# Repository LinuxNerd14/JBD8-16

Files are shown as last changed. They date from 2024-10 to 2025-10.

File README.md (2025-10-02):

# The JBD8-16
Current Deign
A computer with the skeleton of the BE6502 by the revered [Ben Eater](https://eater.net/) with the ultimate goal of running DOOM and making a decent platform for programing in asembly or C at a very fundemental level.

    This computer is currently still deep in hardware development but has a diverse set of planned features like hardware based random numbers and way more RAM than what is reasonable along with an implimentation of the VERA by the [8BitGuy](https://www.the8bitguy.com/).

This is by far not a finished project as these features awaiting implimentation:

1. Memory bank
2. Proper random number generator
3. Micro SD card
4. Better display or VGA output
5. Easily reproducable PCB's

List of contributers:

1. [Brian Dean Ullery](https://github.com/NonzeroCornet)

2. [Joshua Lin Yuan]([LinuxNerd14 (Joshua Yuan) · GitHub](https://github.com/LinuxNerd14))

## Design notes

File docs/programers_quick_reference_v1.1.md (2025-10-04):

Quick Refrence guide for addresses:
See docs for details
VIA:
	$4460 = In/Oout Register B
	$4461 = In/Out Register A 
	$4462 = Data Direction for register B
	$463 = Data Direction for register A
	$4464 = Timer 1 Low-Order Latches and Low-Order Counter 
	$4465 = T1 High-Order Counter
	$4466 = T1 Low-Order Latches
	$4467 = T1 High-Order Latches
	$4468 = T2 Low-Order Latches and Low-Order Counter
	$4469 = T2 High-Order Counter
	$446a = Shift Register
	$446b = Auxiliary Control Register
	$446c = Peripheral Control Register
	$446d = Interrupt Flag Register
	$446e = Interrupt Enable Register
	$446f = Same as 4461 except for no handshake

SERIAL PORT:
	$4470 = UART Data
	$4471 = UART Status
	$4472 = UART Command
	$4473 = UART control

TO FIX THE HARDWARE BUG. Wait a certain time based on cpu clock speed.
This equation sets the value needed for the below code to set the perfect delay. If in doubt, just max it out.
~~~
X = ((1/[BAUD RATE]) * ([CPU clock in Hz]) * 10)/5.208
~~~
This is just a sample piece of code. You can try to implient it if you want but I would recommend making your own for your situation.
~~~
tx_delay:
 ldx #$ff   ; deleay determined by baud rate and cpu clok equation is below to set proper number
tx_delay_1:; ((1/[BAUD RATE]) * ([CPU clok in Hz]) * 10)/5.208 = value to load into X; be sure to round up to the nearest whole number
 dex
 bne tx_delay_1
~~~

Fixed table in hex, inclusive   sector size decimal		sector size hex
ROM     C180 > FFFF             16000				3E80 
SCM     4480 > C17F             32000				7D00
MISC    4474 > 447F             12				C
UART    4470 > 4473             4				4
VIA     4460 > 446F             16				10
VERA    4440 > 445F             32				20
RAND    443F                    1				1
CS      443E                    1(ACTIVE HIGH in hardware)	1
OS      0000 > 443D             17470				443E

In Binary , inclusive(Only useful for hardware development)
ROM     1100-0001-1000-0000  >  1111-1111-1111-1111
SCM     0100-0100-1000-0000  >  1100-0001-0111-1111
MISC    0100-0100-0111-0100  >  0100-0100-0111-1111
UART    0100-0100-0111-0000  >  0100-0100-0111-0011
VIA     0100-0100-0110-0000  >  0100-0100-0110-1111
VERA    0100-0100-0100-0000  >  0100-0100-0101-1111
RAND    0100-0100-0011-1111
CS      0100-0100-0011-1110
OS      0000-0000-0000-0000  >  0100-0100-0011-1101xx

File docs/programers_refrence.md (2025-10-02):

Quick Refrence guide for addresses:
See docs for details
VIA:
	$4460 = In/Oout Register B
	$4461 = In/Out Register A 
	$4462 = Data Direction for register B
	$463 = Data Direction for register A
	$4464 = Timer 1 Low-Order Latches and Low-Order Counter 
	$4465 = T1 High-Order Counter
	$4466 = T1 Low-Order Latches
	$4467 = T1 High-Order Latches
	$4468 = T2 Low-Order Latches and Low-Order Counter
	$4469 = T2 High-Order Counter
	$446a = Shift Register
	$446b = Auxiliary Control Register
	$446c = Peripheral Control Register
	$446d = Interrupt Flag Register
	$446e = Interrupt Enable Register
	$446f = Same as 4461 except for no handshake

SERIAL PORT:
	$4470 = UART Data
	$4471 = UART Status
	$4472 = UART Command
	$4473 = UART control

TO FIX THE HARDWARE BUG. Wait a certain time based on cpu clock speed.
This equation sets the value needed for the below code to set the perfect delay. If in doubt, just max it out.
~~~
X = ((1/[BAUD RATE]) * ([CPU clock in Hz]) * 10)/5.208
~~~
~~~
tx_delay:
 ldx #$ff   ; deleay determined by baud rate and cpu clok equation is below to set proper number
tx_delay_1:; ((1/[BAUD RATE]) * ([CPU clok in Hz]) * 10)/5.208 = value to load into X; be sure to round up to the nearest whole number
 dex
 bne tx_delay_1
~~~

Fixed table in hex, inclusive   sector size
ROM     C180 > FFFF             16000 
SCM     4480 > C17F             32000 
MISC    4474 > 447F             12
UART    4470 > 4473             4
VIA     4460 > 446F             16
VERA    4440 > 445F             32
RAND    443F                    1
CS      443E                    1(ACTIVE HIGH in hardware)
OS      0000 > 443D             17470

In Binary , inclusive(Only useful for hardware development)
ROM     1100-0001-1000-0000  >  1111-1111-1111-1111
SCM     0100-0100-1000-0000  >  1100-0001-0111-1111
MISC    0100-0100-0111-0100  >  0100-0100-0111-1111
UART    0100-0100-0111-0000  >  0100-0100-0111-0011
VIA     0100-0100-0110-0000  >  0100-0100-0110-1111
VERA    0100-0100-0100-0000  >  0100-0100-0101-1111
RAND    0100-0100-0011-1111
CS      0100-0100-0011-1110
OS      0000-0000-0000-0000  >  0100-0100-0011-1101xx

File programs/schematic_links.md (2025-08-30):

# 6502 Bread Board Project
This a collection of stuff that could be useful in the prgraming and development of my breadboard project.

Documentation for all the chips on the breadboard:
65C02 Microprocessor: 
https://eater.net/datasheets/w65c02s.pdf

Versatile Interface Adapter(VIA)(IO): 
https://eater.net/datasheets/w65c22.pdf

Asynchronous Communications Interface Adapter(ACIA)(Serial Port):
https://eater.net/datasheets/w65c51n.pdf

LCD Display(This is the controller for the LCD): 
https://eater.net/datasheets/HD44780.pdf

Quad 2-Input NAND Gate(For banking logic): 
https://eater.net/datasheets/74hc00.pdf

AT28C256(Main ROM): 
https://eater.net/datasheets/28c256.pdf

HM62256B-7(Main RAM): 
https://eater.net/datasheets/hm62256b.pdf

VASM compiler:
http://sun.hasenbraten.de/vasm/index.php?view=relsrc

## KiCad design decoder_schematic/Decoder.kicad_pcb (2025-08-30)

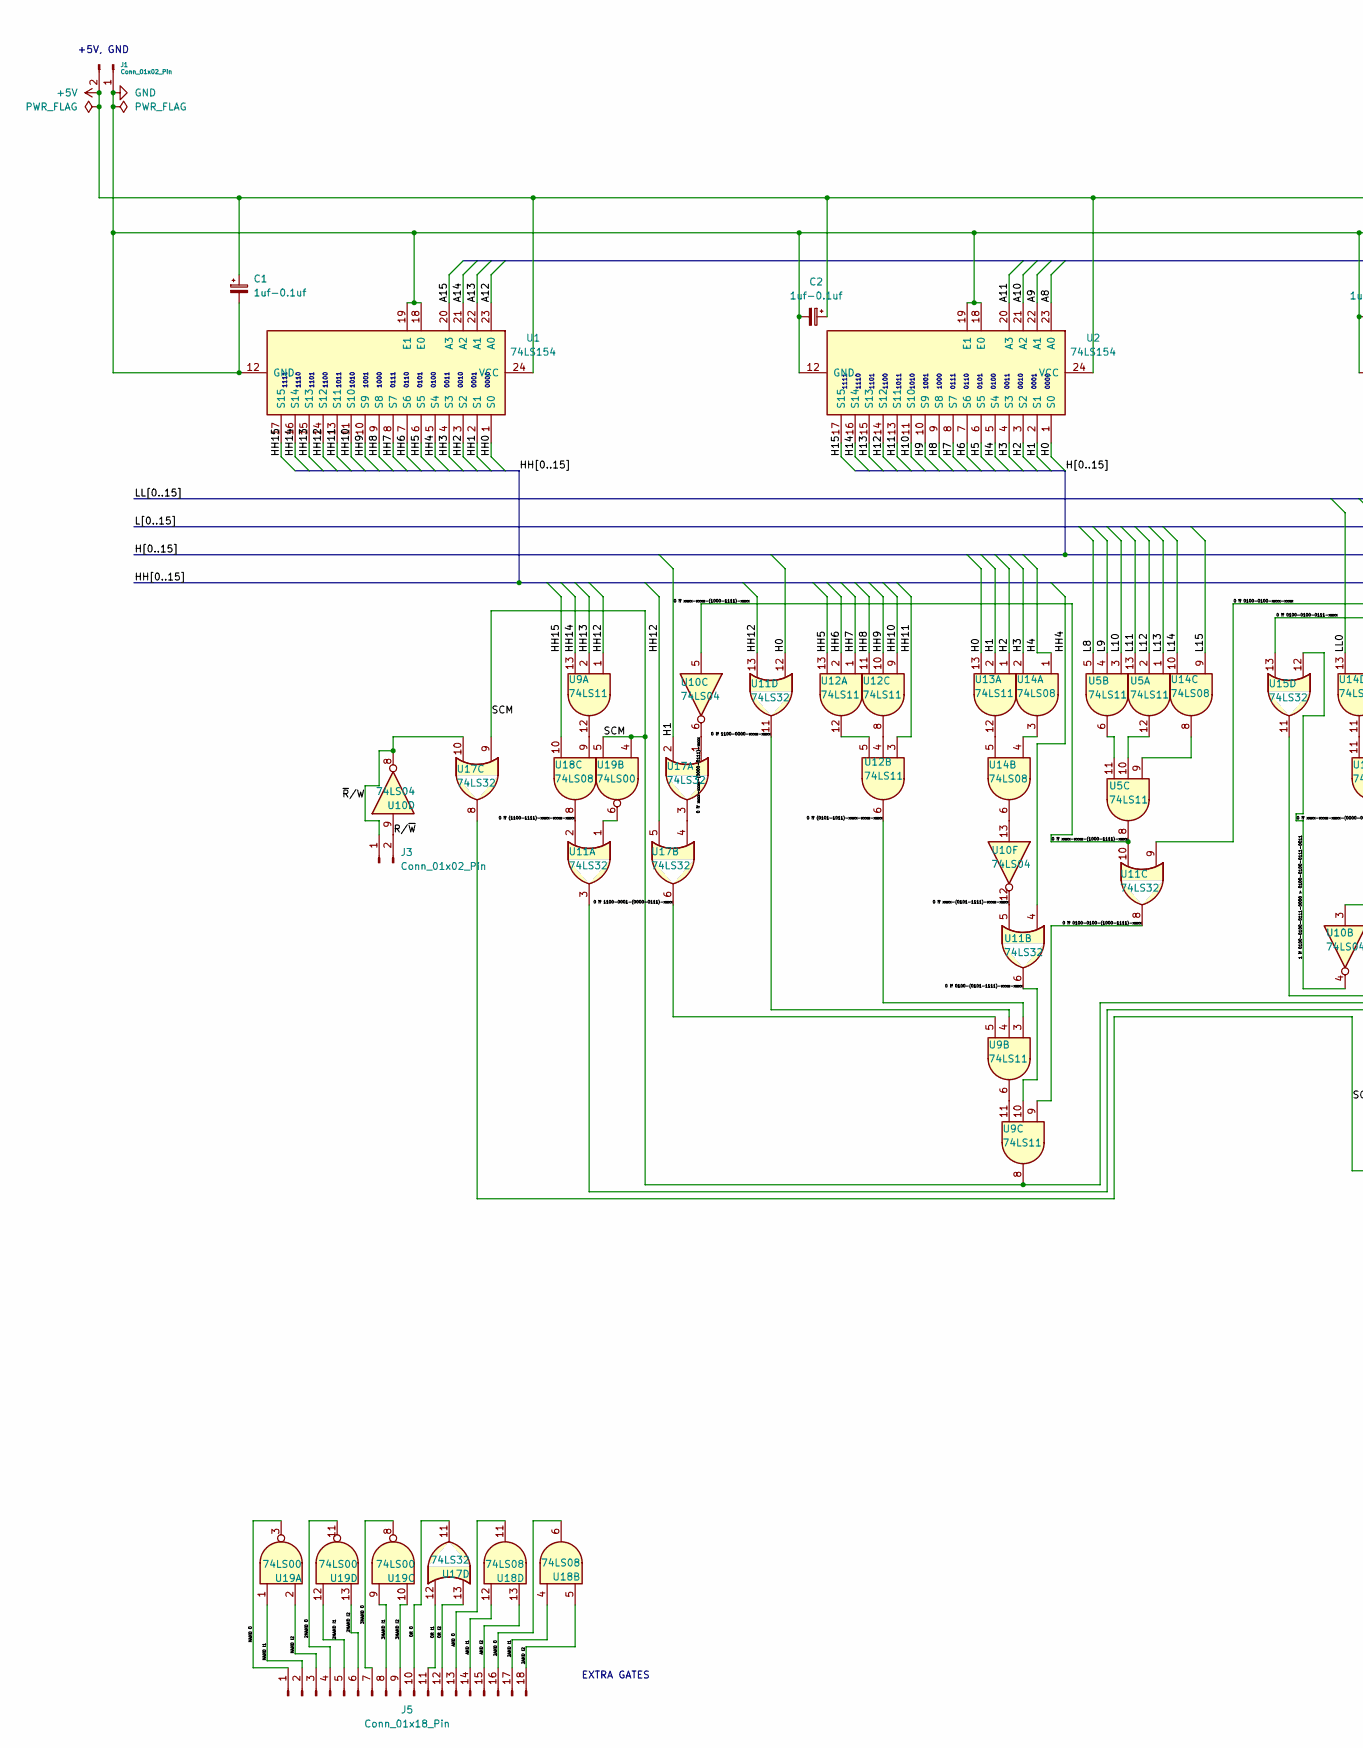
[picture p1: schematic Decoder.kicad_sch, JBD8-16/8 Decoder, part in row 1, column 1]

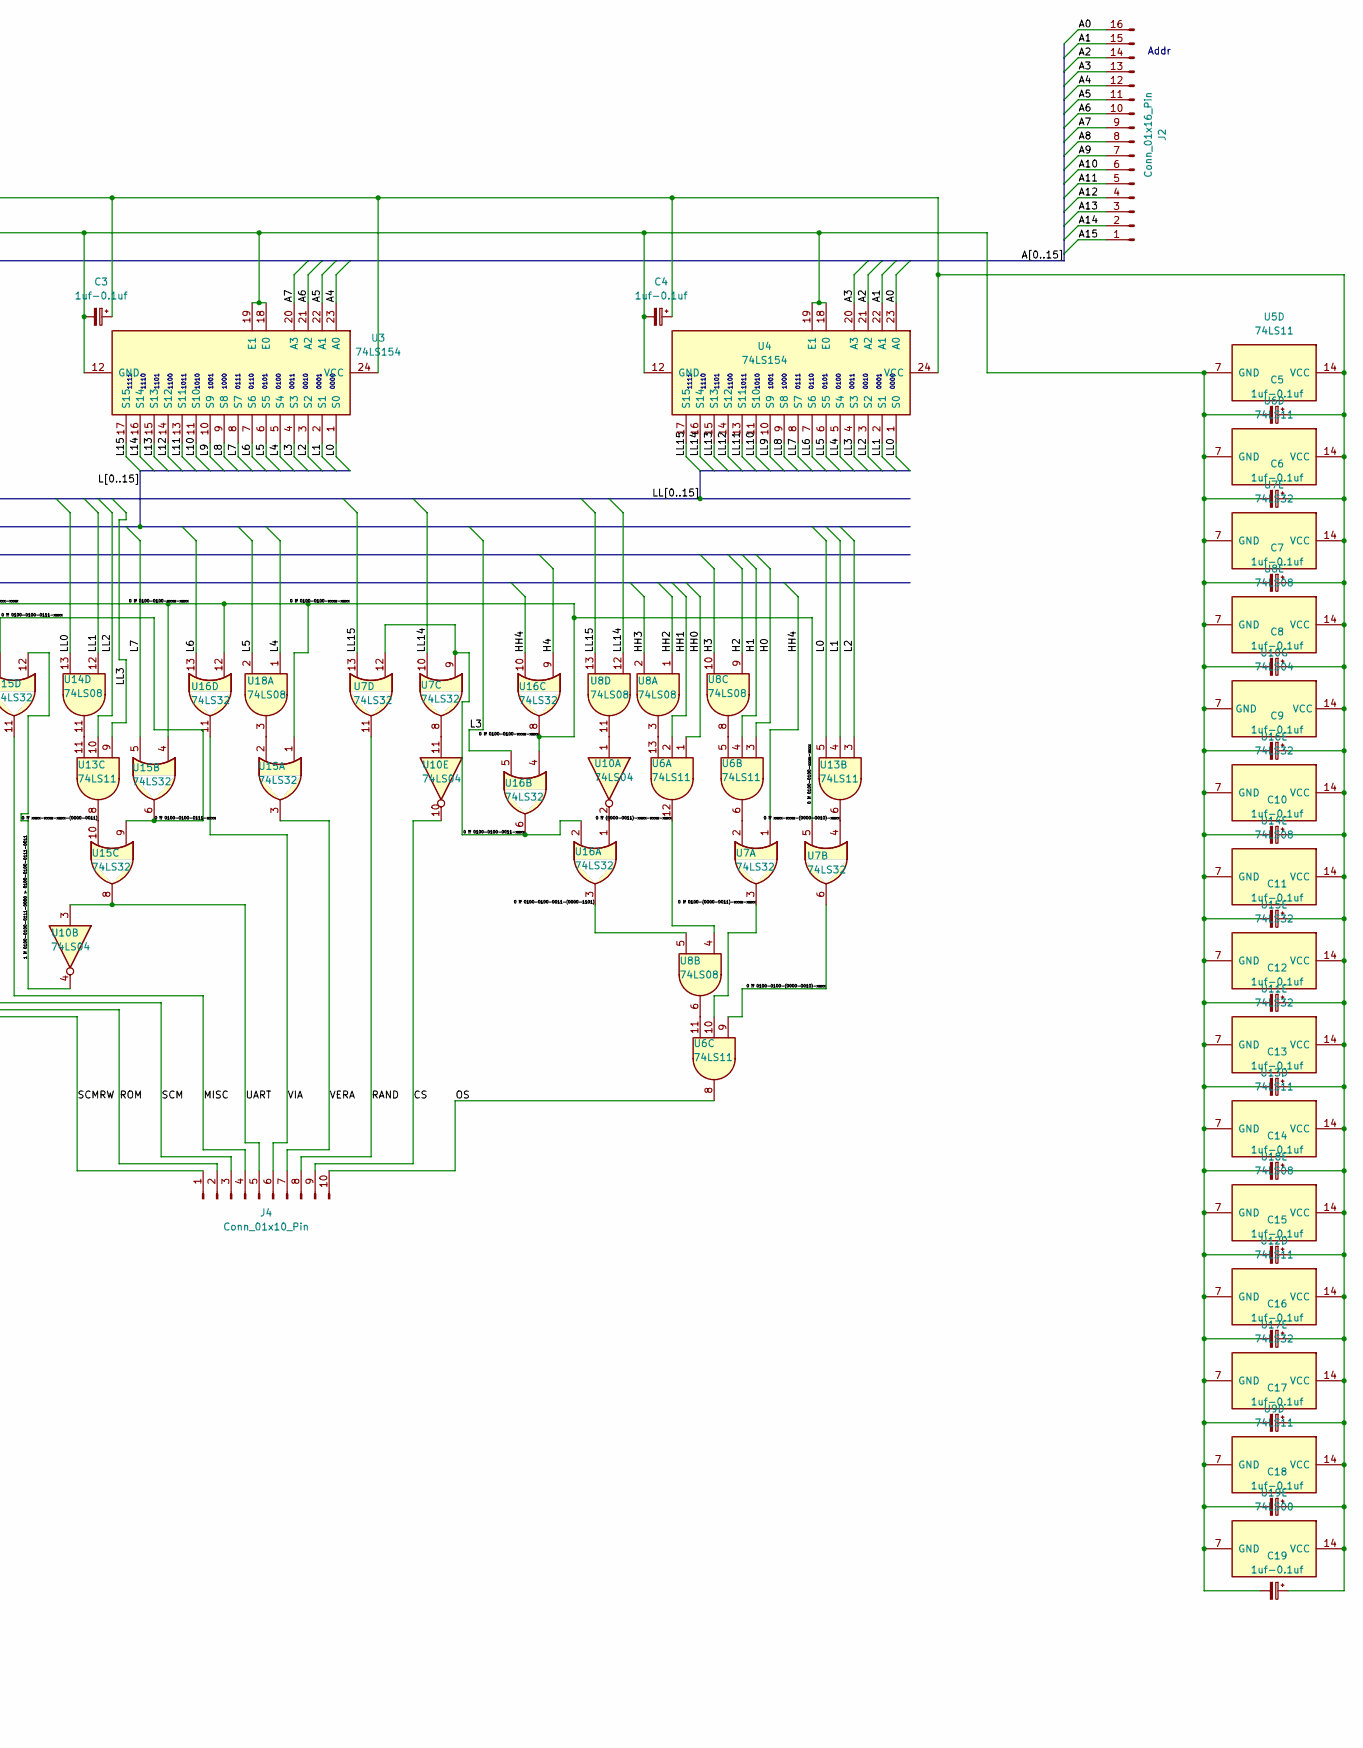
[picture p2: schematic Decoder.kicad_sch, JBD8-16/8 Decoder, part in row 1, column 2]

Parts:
C1, C2, C3, C4, C5, C6, C7, C8, C9, C10, C11, C12, C13, C14, C15, C16, C17, C18, C19: 1uf-0.1uf; CP_Radial_Tantal_D5.0mm_P2.50mm
J1, J3: Conn_01x02_Pin; PinHeader_1x02_P2.54mm_Vertical
J2: Conn_01x16_Pin; PinHeader_1x16_P2.54mm_Vertical
J4: Conn_01x10_Pin; PinHeader_1x10_P2.54mm_Vertical
J5: Conn_01x18_Pin; PinHeader_1x18_P2.54mm_Vertical
U1, U2, U3, U4: 74LS154; DIP-24_W7.62mm_Socket
U5, U6, U9, U12, U13: 74LS11; DIP-14_W7.62mm_Socket
U7, U11, U15, U16, U17: 74LS32; DIP-14_W7.62mm_Socket
U8, U14, U18: 74LS08; DIP-14_W7.62mm_Socket
U10: 74LS04; DIP-14_W7.62mm_Socket
U19: 74LS00; DIP-14_W7.62mm_Socket

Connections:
+5V: C1.1, C2.1, C3.1, C4.1, C5.1, C6.1, C7.1, C8.1, C9.1, C10.1, C11.1, C12.1, C13.1, C14.1, C15.1, C16.1, C17.1, C18.1, C19.1, J1.2, U1.24 (VCC), U2.24 (VCC), U3.24 (VCC), U4.24 (VCC), U5.14 (VCC), U6.14 (VCC), U7.14 (VCC), U8.14 (VCC), U9.14 (VCC), U10.14 (VCC), U11.14 (VCC), U12.14 (VCC), U13.14 (VCC), U14.14 (VCC), U15.14 (VCC), U16.14 (VCC), U17.14 (VCC), U18.14 (VCC), U19.14 (VCC)
/0 if 0100-0100-0011-(0000-1101): U8.5, U16.3
/0 if 0100-0100-0011-xxxx: U7.9, U7.12, U16.2, U16.6
/0 if 0100-0100-0111-xxxx: U15.6, U15.9, U15.13
/0 if 0100-0100-(0000-0010)-xxxx: U6.9, U7.6
/0 if 0100-0100-(1000-1111)-xxxx: U9.9, U11.8
/0 if 0100-0100-xxxx-xxxx: U7.5, U11.9, U15.1, U15.4, U16.4, U16.8, U16.12
/0 if 0100-(0000-0011)-xxxx-xxxx: U6.10, U7.3
/0 if 0100-(0101-1111)-xxxx-xxxx: U9.10, U11.6
/0 if 1100-0000-xxxx-xxxx: U9.4, U11.11
/0 if 1100-0001-(0000-0111)-xxxx: U9.5, U17.6
/0 if (0000-0011)-xxxx-xxxx-xxxx: U6.12, U8.4
/0 if (0101-1011)-xxxx-xxxx-xxxx: U9.3, U12.6
/0 if (1100-1111)-xxxx-xxxx-xxxx: U11.2, U18.8
/0 if xxxx-(0101-1111)-xxxx-xxxx: U10.12, U11.5
/0 if xxxx-xxxx-(0000-0010)-xxxx: U7.4, U13.6
/0 if xxxx-xxxx-(0000-0111)-xxxx: U10.6, U17.1
/0 if xxxx-xxxx-(1000-1111)-xxxx: U5.8, U10.5, U11.10
/0 if xxxx-xxxx-xxxx-(0000-0011): U13.8, U15.10
/1 if 0100-0100-0111-0000 > 0100-0100-0111-0011: U10.4, U15.12
/2AND I1: J5.17, U18.4
/2AND I2: J5.18, U18.5
/2AND O: J5.16, U18.6
/2NAND I1: J5.5, U19.12
/2NAND I2: J5.6, U19.13
/2NAND O: J5.4, U19.11
/3NAND I1: J5.8, U19.9
/3NAND I2: J5.9, U19.10
/3NAND O: J5.7, U19.8
/A0: J2.16, U4.23 (A0)
/A1: J2.15, U4.22 (A1)
/A2: J2.14, U4.21 (A2)
/A3: J2.13, U4.20 (A3)
/A4: J2.12, U3.23 (A0)
/A5: J2.11, U3.22 (A1)
/A6: J2.10, U3.21 (A2)
/A7: J2.9, U3.20 (A3)
/A8: J2.8, U2.23 (A0)
/A9: J2.7, U2.22 (A1)
/A10: J2.6, U2.21 (A2)
/A11: J2.5, U2.20 (A3)
/A12: J2.4, U1.23 (A0)
/A13: J2.3, U1.22 (A1)
/A14: J2.2, U1.21 (A2)
/A15: J2.1, U1.20 (A3)
/AND I1: J5.14, U18.12
/AND I2: J5.15, U18.13
/AND O: J5.13, U18.11
/CS: J4.9, U10.10
/H0: U2.1 (S0), U6.3, U11.12, U13.13
/H1: U2.2 (S1), U6.4, U13.2, U17.2
/H2: U2.3 (S2), U8.9, U13.1
/H3: U2.4 (S3), U8.10, U14.2
/H4: U2.5 (S4), U14.1, U16.9
/H5: U2.6 (S5)
/H6: U2.7 (S6)
/H7: U2.8 (S7)
/H8: U2.9 (S8)
/H9: U2.10 (S9)
/H10: U2.11 (S10)
/H11: U2.13 (S11)
/H12: U2.14 (S12)
/H13: U2.15 (S13)
/H14: U2.16 (S14)
/H15: U2.17 (S15)
/HH0: U1.1 (S0), U6.1
/HH1: U1.2 (S1), U6.2
/HH2: U1.3 (S2), U8.1
/HH3: U1.4 (S3), U8.2
/HH4: U1.5 (S4), U7.1, U11.4, U16.10
/HH5: U1.6 (S5), U12.13
/HH6: U1.7 (S6), U12.2
/HH7: U1.8 (S7), U12.1
/HH8: U1.9 (S8), U12.11
/HH9: U1.10 (S9), U12.10
/HH10: U1.11 (S10), U12.9
/HH11: U1.13 (S11), U12.3
/HH12: U1.14 (S12), U9.1, U11.13, U17.5
/HH13: U1.15 (S13), U9.2
/HH14: U1.16 (S14), U9.13
/HH15: U1.17 (S15), U18.10
/L0: U3.1 (S0), U13.5
/L1: U3.2 (S1), U13.4
/L2: U3.3 (S2), U13.3
/L3: U3.4 (S3), U16.5
/L4: U3.5 (S4), U18.1
/L5: U3.6 (S5), U18.2
/L6: U3.7 (S6), U16.13
/L7: U3.8 (S7), U15.5
/L8: U3.9 (S8), U5.5
/L9: U3.10 (S9), U5.4
/L10: U3.11 (S10), U5.3
/L11: U3.13 (S11), U5.13
/L12: U3.14 (S12), U5.2
/L13: U3.15 (S13), U5.1
/L14: U3.16 (S14), U14.10
/L15: U3.17 (S15), U14.9
/LL0: U4.1 (S0), U14.13
/LL1: U4.2 (S1), U14.12
/LL2: U4.3 (S2), U13.10
/LL3: U4.4 (S3), U13.9
/LL4: U4.5 (S4)
/LL5: U4.6 (S5)
/LL6: U4.7 (S6)
/LL7: U4.8 (S7)
/LL8: U4.9 (S8)
/LL9: U4.10 (S9)
/LL10: U4.11 (S10)
/LL11: U4.13 (S11)
/LL12: U4.14 (S12)
/LL13: U4.15 (S13)
/LL14: U4.16 (S14), U7.10, U8.12
/LL15: U4.17 (S15), U7.13, U8.13
/MISC: J4.4, U15.11
/NAND I1: J5.2, U19.1
/NAND I2: J5.3, U19.2
/NAND O: J5.1, U19.3
/OR I1: J5.11, U17.12
/OR I2: J5.12, U17.13
/OR O: J5.10, U17.11
/OS: J4.10, U6.8
/RAND: J4.8, U7.11
/ROM: J4.2, U11.3
/R/~W: J3.2, U10.9
/SCM: J4.3, U9.8, U17.9, U19.4, U19.5
/SCMRW: J4.1, U17.8
/UART: J4.5, U10.3, U15.8
/VERA: J4.7, U15.3
/VIA: J4.6, U16.11
/~R/W: J3.1, U10.8, U17.10
GND: C1.2, C2.2, C3.2, C4.2, C5.2, C6.2, C7.2, C8.2, C9.2, C10.2, C11.2, C12.2, C13.2, C14.2, C15.2, C16.2, C17.2, C18.2, C19.2, J1.1, U1.12 (GND), U1.18 (E0), U1.19 (E1), U2.12 (GND), U2.18 (E0), U2.19 (E1), U3.12 (GND), U3.18 (E0), U3.19 (E1), U4.12 (GND), U4.18 (E0), U4.19 (E1), U5.7 (GND), U6.7 (GND), U7.7 (GND), U8.7 (GND), U9.7 (GND), U10.7 (GND), U11.7 (GND), U12.7 (GND), U13.7 (GND), U14.7 (GND), U15.7 (GND), U16.7 (GND), U17.7 (GND), U18.7 (GND), U19.7 (GND)
unnamed: U5.10, U5.12
unnamed: U5.6, U5.11
unnamed: U6.5, U8.8
unnamed: U6.6, U7.2
unnamed: U6.11, U8.6
unnamed: U6.13, U8.3
unnamed: U9.6, U9.11
unnamed: U8.11, U10.1
unnamed: U10.2, U16.1
unnamed: U7.8, U10.11
unnamed: U10.13, U14.6
unnamed: U11.1, U19.6
unnamed: U12.4, U12.8
unnamed: U12.5, U12.12
unnamed: U13.11, U14.11
unnamed: U13.12, U14.5
unnamed: U14.3, U14.4
unnamed: U5.9, U14.8
unnamed: U15.2, U18.3
unnamed: U17.3, U17.4
unnamed: U9.12, U18.9

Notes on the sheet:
Addr
EXTRA GATES
1111 1110 1101 1100 1011 1010 1001 1000 0111 0110 0101 0100 0011 0010 0001 0000
+5V, GND

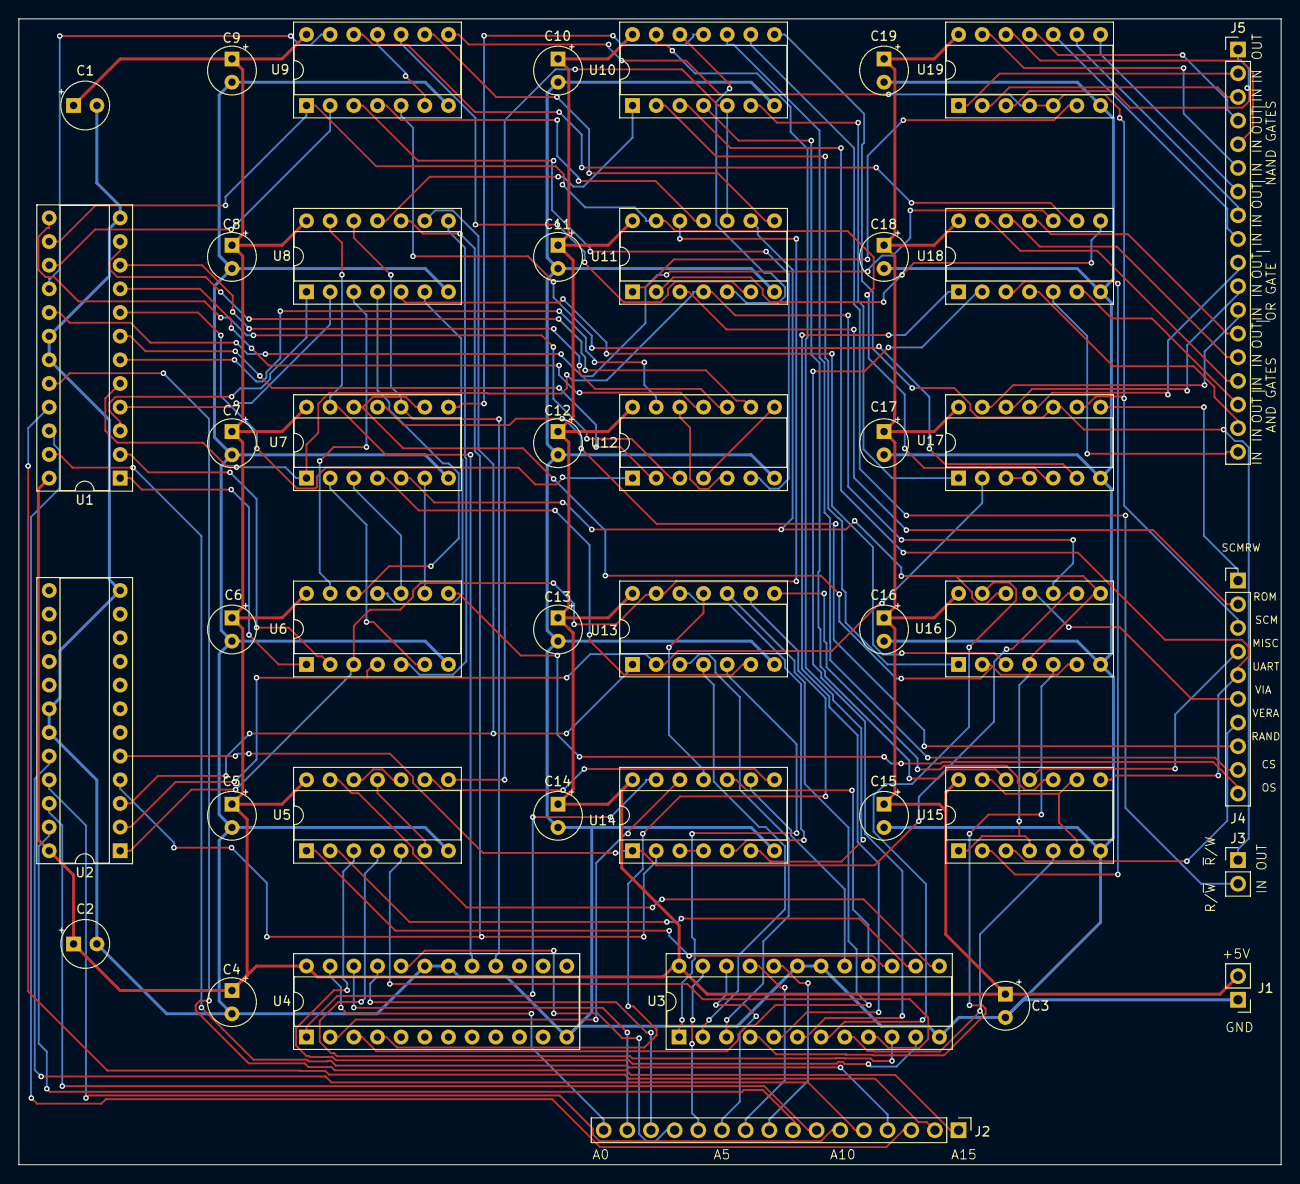
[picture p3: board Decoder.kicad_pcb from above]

Board: 2 copper layers, 135.5 x 123.0 mm, 43 parts (0 on the bottom side), 131 nets.

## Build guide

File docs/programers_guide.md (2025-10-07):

# Programming Reference Guide for the JBD8-16 Computer

## Table of Contents:

1. Introduction

2. System Overview

3. Programming

## 1: Introduction

- **What this computer is**  
  A short description of the computer, its purpose (general-purpose? educational? experimental?), and why it’s interesting to program.

- **Target audience**  
  Clarify whether it’s meant for beginners in assembly, hobbyists, or advanced programmers.

## 2: System Overview

- **CPU**: Name (e.g., WDC 65C02, 6502, custom CPU), clock speed, instruction set basics.

- **Memory map**: A clear diagram or table showing where RAM, ROM, I/O devices, banked memory, etc. live in the address space.

- **I/O devices**: Serial port, display, input devices, etc. (what they are, where they are mapped, how to access them).

- **Special features**: Memory banking, random number generator, interrupt handling, etc.

## 3: Programming

#### Overview

This computer can be programmed in straight up in 65C02 assembly or C using cc65. The opcodes for assembly can be found in the documentation for the CPU [here](https://www.westerndesigncenter.com/wdc/documentation/w65c02s.pdf) or you can [also go here]([6502.org Tutorials: 65C02 Opcodes](http://www.6502.org/tutorials/65c02opcodes.html)) for a more human-readable explanation and description of 65C02 assembly. Programming in C is not implemented yet but will be soon. The "programs" directory is organized by memory decoder version since differences in it fundamentally change the programming of the computer. As of now the latest is V1.1 but use whatever is appropriate for your hardware.

### Making Programs

#### 65C02 Assembly

Writing code is a three-step process. In order: writing the program; compiling the program; padding the program. After these steps are completed, you should hopefully have a valid binary file that you can write to either the EEPROM or a micro SD card. 
The compiler of choice is [ca65](https://cc65.github.io/doc/ca65.html) and its sibling ld65. ca65 compiles the program and ld65 being the [linker](https://en.wikipedia.org/wiki/Linker_(computing)), links it and thus produces a binary file. 

###### Writing a Program
In the future there will be two places to put programs on the computer. A micro SD card and the EEPROM. Right now only the EEPROM currently works and thus we will be writing a program assuming we are writing to the EEPROM.
For every version of the decoder, there will be the necessary configuration files in the decoder directory. There you will find in ca65 directory a MemoryMap.cfg which tells ld65 where all the sections of memory are(you can learn more [here](https://www.cc65.org/doc/ld65-5.html) and the programmer's quick reference will have memory locations). There is also a pad.sh file that will be used later.
Once there, make a program file that ends with a .asm(you can use any random file extension but .asm is the norm in this project) and open it with your favorite code editor.
I will not tell you how to write assembly as you can [just go here](http://www.6502.org/tutorials/65c02opcodes.html) but I will tell you what you need for this computer.
If you use the MemoryMap.cfg that I provide which I recommend for beginners then you will need some certain things in your code namely:
~~~(65C02 asm)
.segment "VECTORS"
		.word	$<NMIB>
		.word	$<RESET VECTOR>
		.word	$<IRQB>
~~~
This goes at the end of your program and tells ld65 where three vectors are. I will give a brief explanation of these vectors descending by importance.
* **The Reset Vector**(pin 40) tells the CPU where to go to start program execution after the CPU is told to reset by a low signal to pin 40 after 7 clock cycles. For this computer this is always at the start of ROM(for the v1.1 decoder that address happens to be $C180).
* **IRQB**(interrupt request, pin 4) This is where the CPU goes whenever an interrupt request is submitted (as long as interrupts weren't blocked by the opcode SEI). Interrupts come in from other parts of the computer(like the serial port ship also known as the UART) by a low signal input to pin 4 and the interrupt stays low until properly handled. Thus, any code running after an interrupt should be designed to resolve these interrupts. For example: The UART triggers an interrupt because the UART has received data. The code at the IRQB vector then takes the data from the UART and tells the UART that the data has been acquired, and thus the UART stops triggering an interrupt thus handling the interrupt. When making code for handling interrupts it is important to know that all of the other parts of the computer share the same IRQB line. This means when the CPU sees an interrupt the CPU does not know from where it is coming from thus you need to write your IRQB handler to deal with this.
* **NMBI**(None Maskable Interrupt) This is where the CPU goes after receiving an NMBI. This is very similar to IRQB but it can't be blocked by the opcode SEI and the signal is different. IRQB holds the interrupt signal until the interrupt is handled. NMBI sends a single interrupt signal then stops. NMBI is a VERY powerful feature and thus is dangerous. It will interrupt anything at any moment. Thus a time sensitive operation can be completely ruined by this interrupt. Plan accordingly. Fortunately for you the computer does not have the NMBI functional (yet). An example where this feature would be very useful is power lose protection. A sensor in the power supply detects either a power spike or power loss. This interrupts the CPU through NMBI thus ignoring any current operations. The code at the NMBI is made as an emergency shutdown (i.e dumping RAM to storage) before the computer runs out of power (obviously this would require a power supply specially designed for this but this is only an example).
* To know more, look at page nine [here](https://www.westerndesigncenter.com/wdc/documentation/w65c02s.pdf).
  
#### C

Not implemented yet.

### Installing Programs

#### Writing to the EEPROM

~~~bash
minipro -p 28c256 -uP -w FILE_NAME
~~~

#### Writing to the Micro SD Card

Not implemented yet.

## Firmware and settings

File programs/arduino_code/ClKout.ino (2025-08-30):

void setup() {
  // initialize digital pin LED_BUILTIN as an output.
  pinMode(LED_BUILTIN, OUTPUT);
  pinMode(2, INPUT);
}

// the loop function runs over and over again forever
void loop() {
  if (digitalRead(2) == HIGH) {
    digitalWrite(LED_BUILTIN, HIGH);  // turn the LED on (HIGH is the voltage level)
    delay(10);                      // wait for a second
    digitalWrite(LED_BUILTIN, LOW);   // turn the LED off by making the voltage LOW
    delay(10);                      // wait for a second
  }
  else {
    digitalWrite(LED_BUILTIN, HIGH);  // turn the LED on (HIGH is the voltage level)
    delay(250);                      // wait for a second
    digitalWrite(LED_BUILTIN, LOW);   // turn the LED off by making the voltage LOW
    delay(250);                      // wait for a second
  }
}

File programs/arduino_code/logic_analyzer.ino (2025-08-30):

const char ADDR[] = {22, 24, 26, 28, 30, 32, 34, 36, 38, 40, 42, 44, 46, 48, 50, 52};  //52 == A0, 22 == A15
const char DATA[] = {39, 41, 43, 45, 47, 49, 51, 53};   // 53 == D0, 39 == D7
#define CLOCK 2   // pin 2 is clock in
#define READ_WRITE 3
void setup() {
  for (int n = 0; n < 16; n += 1) {
    pinMode(ADDR[n], INPUT);
  }
  for (int n = 0; n < 8; n += 1) {
    pinMode(DATA[n], INPUT);
  }
  pinMode(CLOCK, INPUT);
  pinMode(READ_WRITE, INPUT);

  attachInterrupt(digitalPinToInterrupt(CLOCK), onClock, RISING);
  
  Serial.begin(57600);
}

void onClock() {
  char output[15];

  unsigned int address = 0;
  for (int n = 0; n < 16; n += 1) {
    int bit = digitalRead(ADDR[n]) ? 1 : 0;
    Serial.print(bit);
    address = (address << 1) + bit;
  }
  
  Serial.print("   ");
  
  unsigned int data = 0;
  for (int n = 0; n < 8; n += 1) {
    int bit = digitalRead(DATA[n]) ? 1 : 0;
    Serial.print(bit);
    data = (data << 1) + bit;
  }

  sprintf(output, "   %04x  %c %02x", address, digitalRead(READ_WRITE) ? 'R' : 'W', data);
  Serial.println(output);  
}

void loop() {
}

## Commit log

2024-10-27 worked on SCM
    [JBD8-16.kicad_sch]
2024-11-03 Worked on SCM and README FIX THE GAP IN THE SCM BETWEEN 0000-0110-0001-0000 and 0001-0000-0000-0000
    [JBD8-16.kicad_sch]
2024-11-03 Finished SCM and made the chematic paper larger
    [JBD8-16.kicad_sch]
2024-11-04 Worked on OS mem space, adding of 4th decoder needed
    [JBD8-16.kicad_sch]
2024-11-05 added and image to the README
    [JBD8-16.kicad_sch]
2024-11-06 Almost done with OS mem and reduced the complexity of many sectors uisng another decoder
    [JBD8-16.kicad_sch]
2024-11-06 Worked on OS mem
    [JBD8-16.kicad_sch]
2024-11-06 almost done with ROM and SHM map
    [JBD8-16.kicad_sch]
2024-11-07 FINISHED MEMORY LOGICgit add .git add .!
    [JBD8-16.kicad_sch]
2024-11-07 Worked on the BANK
    [JBD8-16.kicad_sch]
2024-11-08 worked on mem bank
    [JBD8-16.kicad_sch]
2024-11-08 Made the Mem Bank work properly
    [JBD8-16.kicad_sch]
2024-11-08 worked on the CS on some chips
    [JBD8-16.kicad_sch]
2024-11-16 New memory map, New logic, Added VIA, Hooked up a screen and UART, Better memory map table
    [JBD8-16.kicad_sch]
2024-11-16 Fixed untracked symbols
    [JBD8-16.kicad_sch]
2024-11-16 Fixed even more untracked parts
    [JBD8-16.kicad_sch]
2024-11-23 Fixed unconnected VCC on U24
    [JBD8-16.kicad_sch]
2024-11-24 general fixes to decoder
    [JBD8-16.kicad_sch]
2024-11-27 Fixed the decoders being inactive
    [JBD8-16.kicad_sch]
2024-11-27 Many issues with map which have been labeled
    [JBD8-16.kicad_sch]
2024-11-27 Removed unneccasary logic
    [JBD8-16.kicad_sch]
2024-11-27 Made the physiocal layout of the decoder less stupid
    [JBD8-16.kicad_sch]
2024-11-28 THE DECODER WORKSgit add .
    [JBD8-16.kicad_sch]
2024-11-30 IT FRICKING WORKS
    [JBD8-16.kicad_sch]
2024-12-03 Little bits of optimasition in decoder layout
    [JBD8-16.kicad_sch]
2025-02-17 updated image
    [JBD8-16.kicad_sch]
2025-02-23 removed parts that are on another pcb
    [JBD8-16.kicad_sch]
2025-03-17 spring break
    [JBD8-16.kicad_sch]
2025-08-30 Merged all repos asociated with the project
    [Decoder-B_Cu.gbr, Decoder-B_Mask.gbr, Decoder-B_Paste.gbr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]
2025-09-23 Kicad Backups
2025-09-23 Trying to make a ca65 config for the computer memory map along with transfering the SerialPortRoutine.asm code to work with it
    [Memory.cfg, MemoryTEST.cfg]
2025-09-30 Finalized converting the SerialPortRoutine.asm from VASM to ca65
    [Memory.cfg, MemoryMap.cfg]
2025-09-30 Spring Cleaning
    [Decoder-B_Cu.gbr, Decoder-B_Mask.gbr, Decoder-B_Paste.gbr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]
2025-09-30 Even more organization and cleaning
    [Decoder-B_Cu.gbr, Decoder-B_Mask.gbr, Decoder-B_Paste.gbr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]
2025-10-02 more documentation milarky
    [HelloWorld.cfg, bios.cfg, config.cfg]
2025-10-04 added to docs and fixed the pad.sh in v1.1 code
    [MemoryMap.cfg]
